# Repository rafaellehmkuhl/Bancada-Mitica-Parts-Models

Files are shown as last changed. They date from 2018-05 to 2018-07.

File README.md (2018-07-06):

Parts Models

This repository contais all the models for the parts used on the project and construction of Bancada Mitica.

All the parts contained here were designed using Solidworks 2016, and so the models are on .SLDPRT extension.
The models used for 3D printed parts are also exported on STL, so anyone can print.
I'm also going to export the .STEP files in the future, so anyone can edit the parts with other softwares, like Fusion360 or Inventor.

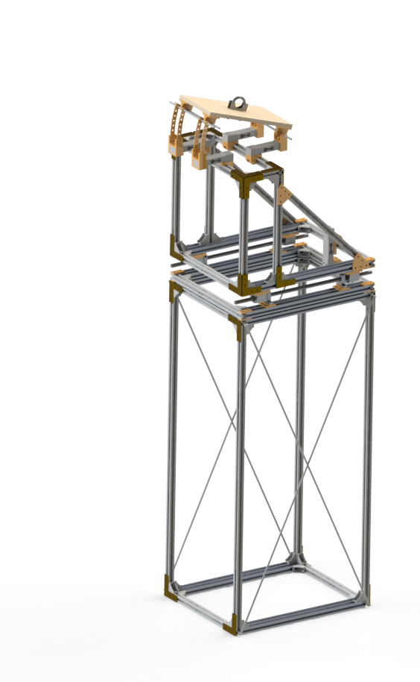
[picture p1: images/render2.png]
Bancada sobre a Torre


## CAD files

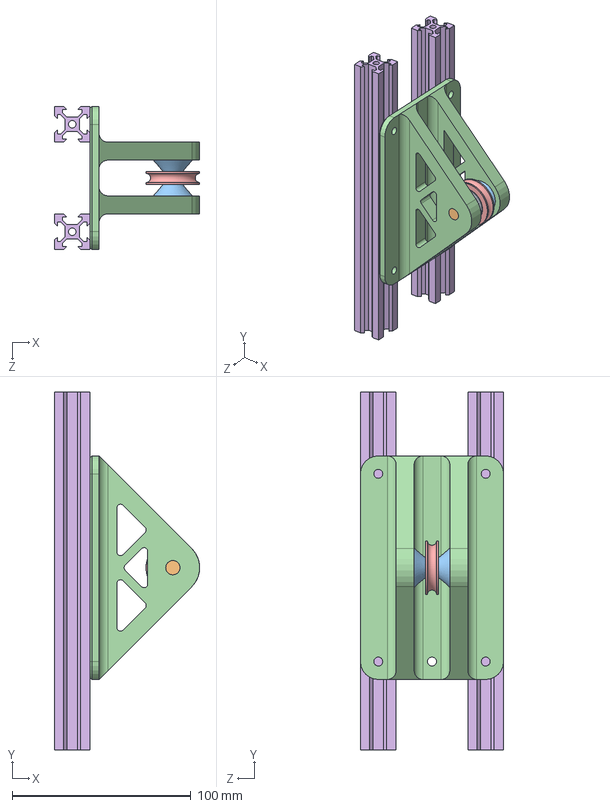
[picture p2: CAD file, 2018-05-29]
Calibraçao/Roldana/Roldana_de_parede.SLDASM
81.2 x 200.0 x 80.0 mm
608RS
Eixo_rolamento
Espaçador_rolamento x 2
Suporte_de_rolamento
Encaixe_corda
Perfil_20x20mm x 2

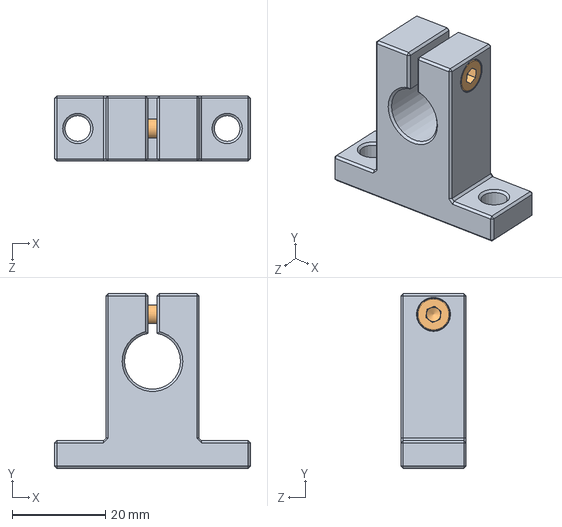
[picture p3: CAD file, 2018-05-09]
Carrinho/Suporte de Eixo SK12/Suporte_SK12.SLDASM
42.0 x 37.5 x 14.0 mm
Shaft support SK12
m4x16

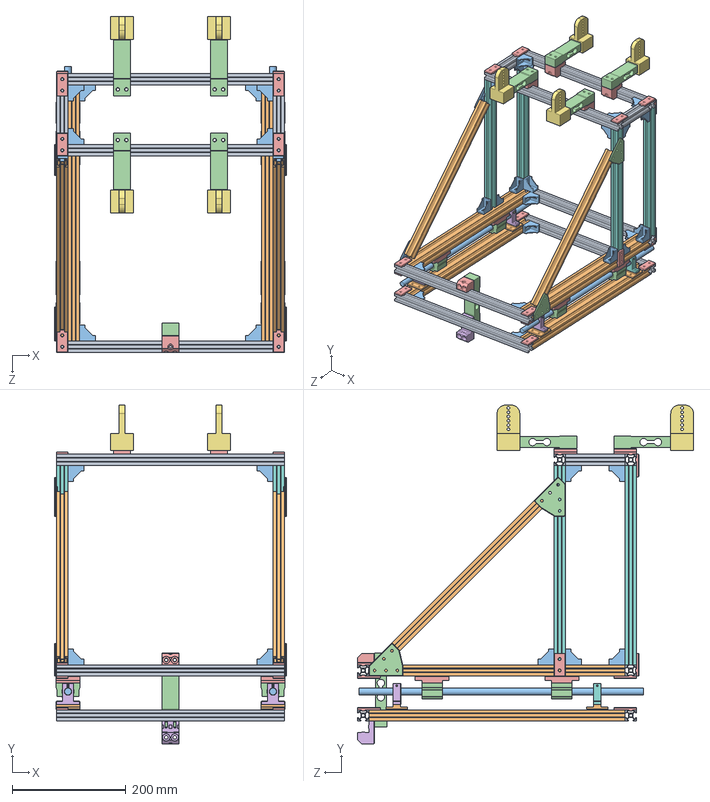
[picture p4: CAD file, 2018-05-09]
Montagens/Balança/Antigas/Balança Final.SLDASM
408.0 x 595.0 x 590.0 mm
20x20x400_profile x 6
20x40x450_profile x 4
cantoneira_20x20 x 28
SC12UU x 4
AdaptadorPillowBlock12 x 4
Shaft support SK12 x 3
m4x16 x 3
EspelharShaft support SK12
Espelharm4x16
AdaptadorSuporteSK12 x 4
EixoLinear12x500mm x 2
load_cell_big_20kg x 5
SuporteCelulaCarga_Reforcado x 5
SuporteCelulaCarga_Reforcado_Ajustavel
EncaixeAsaTraseiro_Alt3 x 4
20x20x350_profile x 4
20x20x105_profile x 2
20x20x410_profile x 2
Placa_lateral_45_esq x 2
Placa_lateral_45_dir x 2
Cantoneira_plana x 20

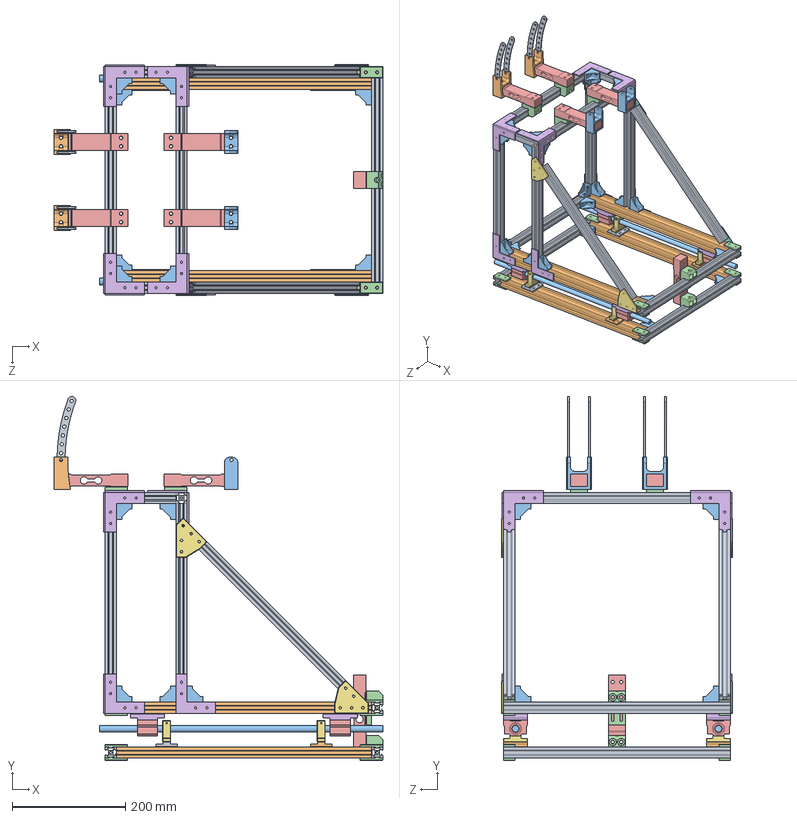
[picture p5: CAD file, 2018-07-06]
Montagens/Balança/Balança.SLDASM
579.5 x 642.0 x 408.0 mm
Perfil_20x20mm x 14
Perfil_20x40mm x 4
Cantoneira_interna_20x20mm x 28
Cantoneira_Plana_impressa_20x40mm x 14
Pillow_Block_SC12UU x 4
Adaptador_para_Pillow_Block_SC12UU x 4
Shaft support SK12 x 4
m4x16 x 4
Adaptador_para_Suporte_SK12_movel x 2
Adaptador_para_Suporte_SK12_fixo x 2
Eixo_Linear_12mm x 2
Suporte_para_Celula_de_Carga_Reforcado x 5
Celula_de_Carga_20kg x 5
Cantoneira_plana_lateral x 16
Placa_Lateral_45graus_impressa_esquerda x 2
Placa_Lateral_45graus_impressa_direita x 2
Peça_de_angulo x 4
Peça_Central x 2
Encaixe_Celula_de_Angulo_Fixo x 2
Suporte_para_Celula_de_Carga_Reforcado_ajustavel

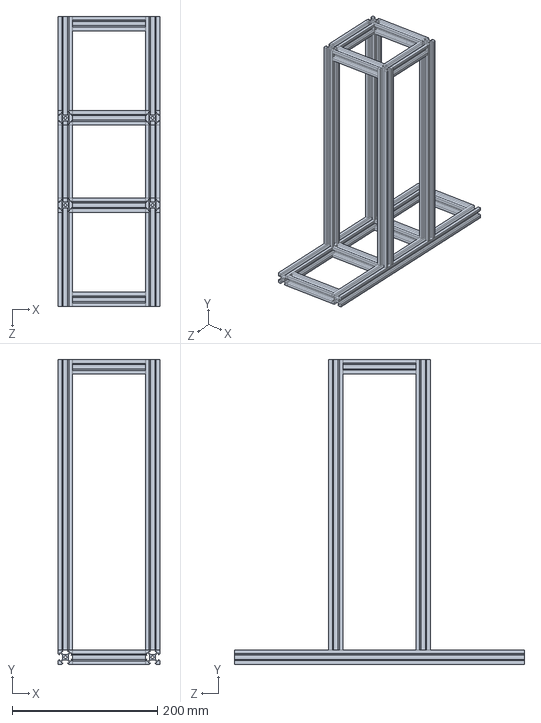
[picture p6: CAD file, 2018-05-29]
Montagens/Calibrador_com_roldana.SLDASM
140.0 x 420.0 x 400.0 mm
Perfil_20x20mm x 14

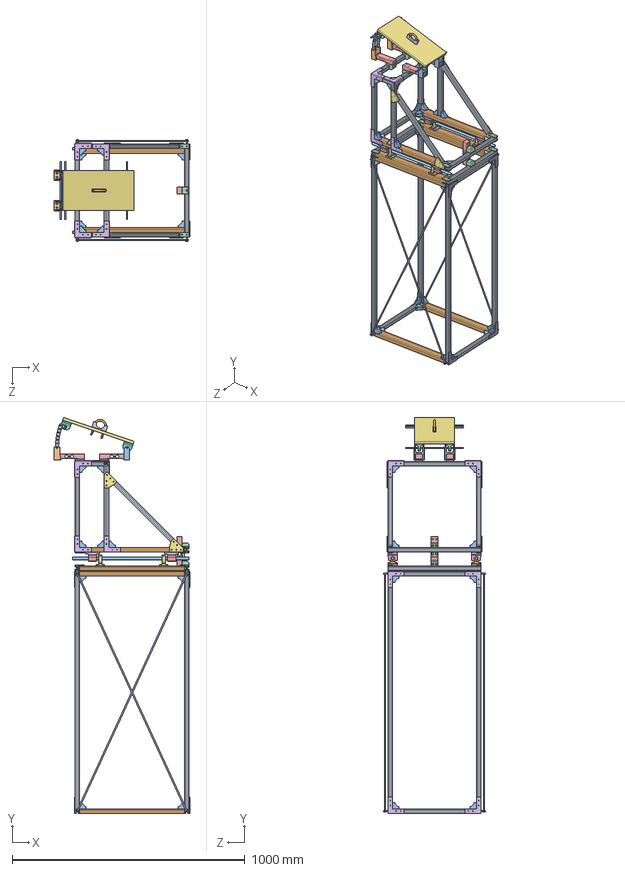
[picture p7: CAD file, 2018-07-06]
Montagens/Montagem completa/Torre_e_balanca.SLDASM
582.5 x 1701.3 x 439.8 mm
Perfil_20x20mm x 22
Perfil_20x40mm x 8
Cantoneira_interna_20x20mm x 52
Cantoneira_Plana_impressa_20x40mm x 14
Pillow_Block_SC12UU x 4
Adaptador_para_Pillow_Block_SC12UU x 4
Shaft support SK12 x 4
m4x16 x 4
Adaptador_para_Suporte_SK12_movel x 2
Adaptador_para_Suporte_SK12_fixo x 2
Eixo_Linear_12mm x 2
Suporte_para_Celula_de_Carga_Reforcado x 5
Celula_de_Carga_20kg x 5
Cantoneira_plana_lateral x 24
Placa_Lateral_45graus_impressa_esquerda x 2
Placa_Lateral_45graus_impressa_direita x 2
Peça_de_angulo x 4
Peça_Central x 2
Encaixe_Celula_de_Angulo_Fixo x 2
Suporte_para_Celula_de_Carga_Reforcado_ajustavel
Parafuso_Olhal_30mm x 8
Cabo_de_aco x 4
Placa
Encaixe_Placa_de_Calibracao x 4
Abracadeira_Grampo_U_Placa_de_Calibracao_Base
Abracadeira_Grampo_U_Placa_de_Calibracao_Argola
Vareta6mm x 3
Extensor x 4

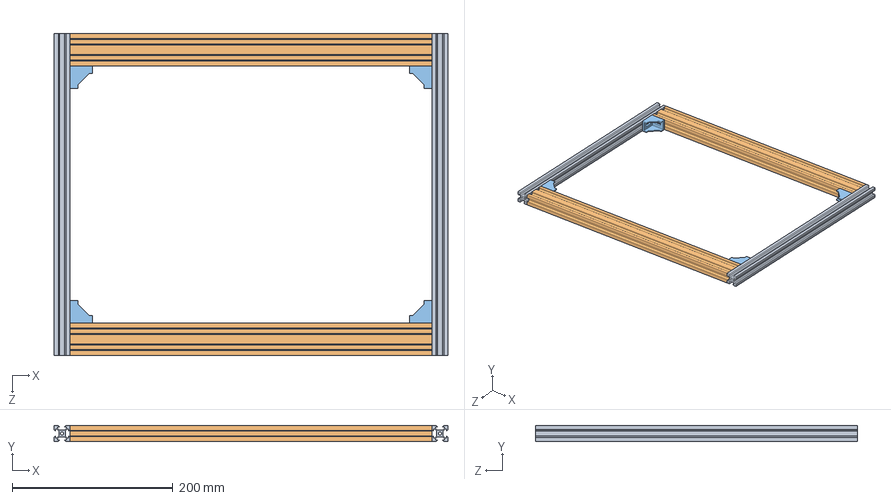
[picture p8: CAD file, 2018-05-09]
Montagens/Quadrado/Quadrado_400x490mm.SLDASM
490.0 x 20.0 x 400.0 mm
Perfil_20x20mm x 2
Perfil_20x40mm x 2
Cantoneira_interna_20x20mm x 4

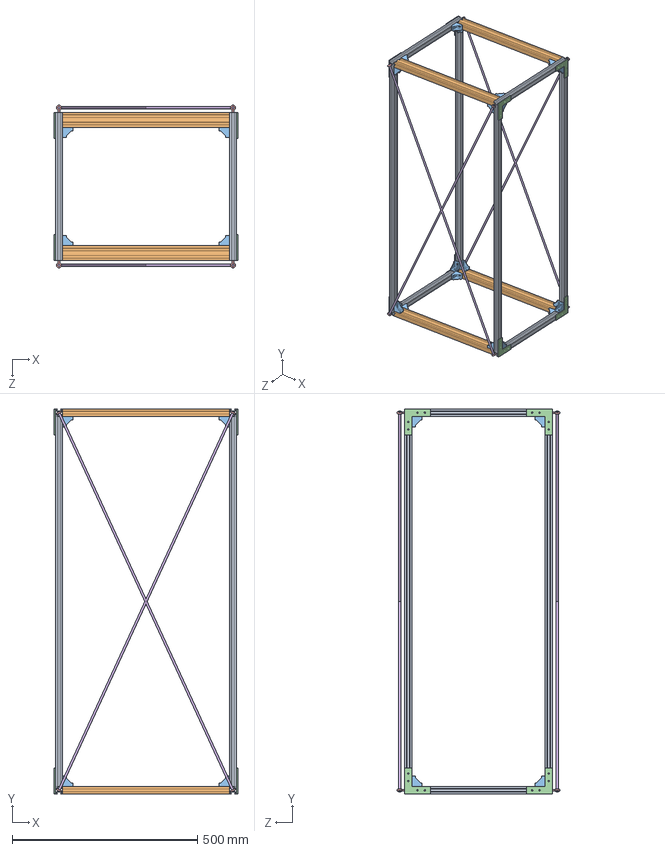
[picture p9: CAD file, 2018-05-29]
Montagens/Torre/Torre.SLDASM
496.0 x 1040.0 x 439.8 mm
Perfil_20x20mm x 8
Perfil_20x40mm x 4
Cantoneira_interna_20x20mm x 24
Cantoneira_plana_lateral x 8
Parafuso_Olhal_30mm x 8
Cabo_de_aco x 4

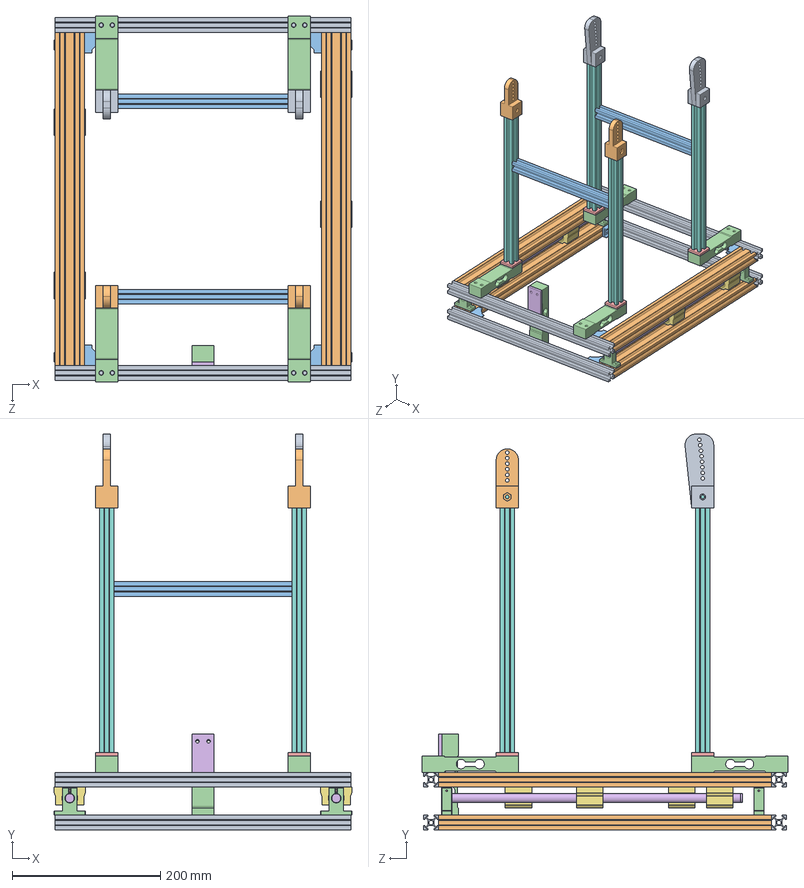
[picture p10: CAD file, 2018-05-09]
Montagens/Balança/Antigas/Balança_Alt2.SLDASM
402.0 x 535.0 x 494.0 mm
20x20x400_profile x 4
20x40x450_profile x 4
cantoneira_20x20 x 8
Shaft support SK12 x 4
m4x16 x 4
EixoLinear12mm x 2
SC12UU x 4
20x20x500_profile x 4
EncaixeAsaDianteiro x 2
EncaixeAsaTraseiro x 2
20x20x200_profile x 2
load_cell_big_20kg x 5
Placa_de_conexao_celula_de_carga x 4
Placa_de_conexao_celula_de_carga_2

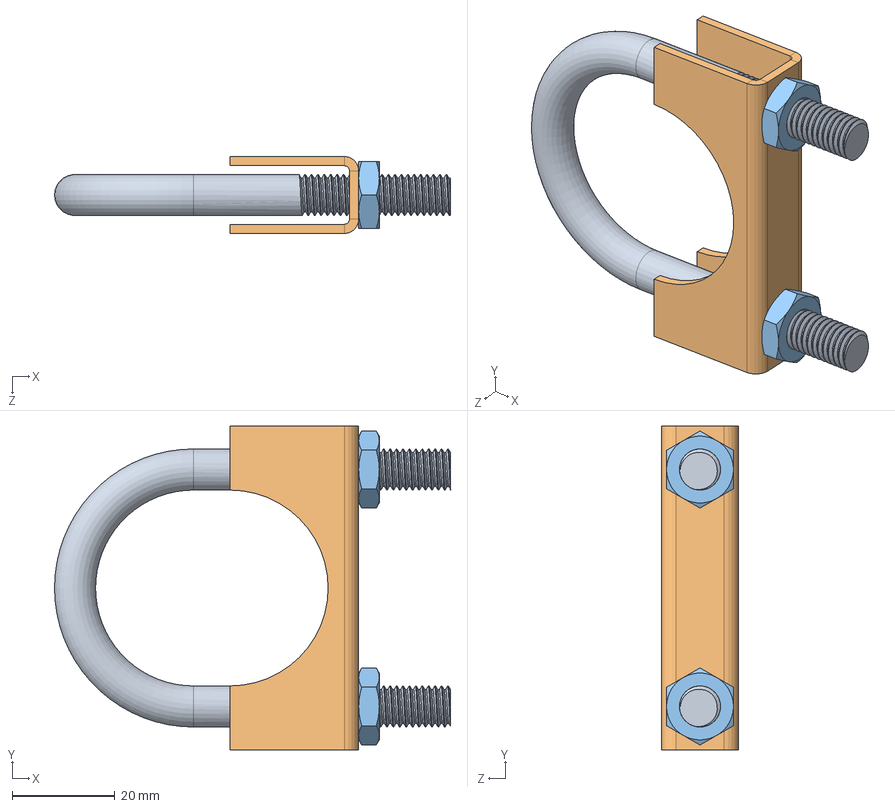
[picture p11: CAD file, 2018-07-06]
Calibraçao/Placa-asa/Abraçadeira/Grampo_Montagem.SLDASM
77.1 x 63.0 x 15.0 mm
Abracadeira_Grampo_U_1.5_
Abracadeira_Grampo_U_1.5_Suporte
hex nut jam_am x 2

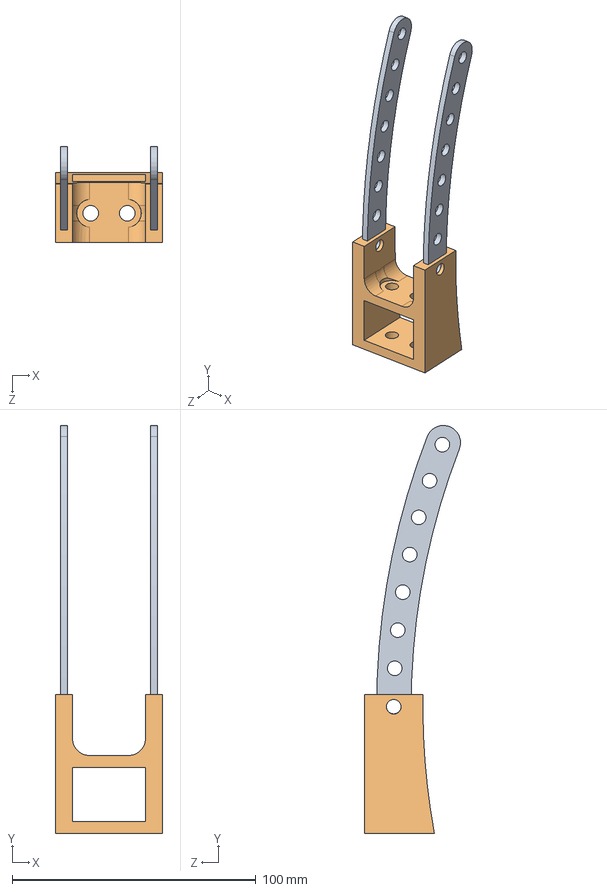
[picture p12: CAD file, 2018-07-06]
Celula de carga/EncaixeCelulaAnguloVariavel/Montagem_Encaixe_Celula_de_Angulo_Variavel.SLDASM
44.0 x 167.5 x 39.4 mm
Peça_de_angulo x 2
Peça_Central

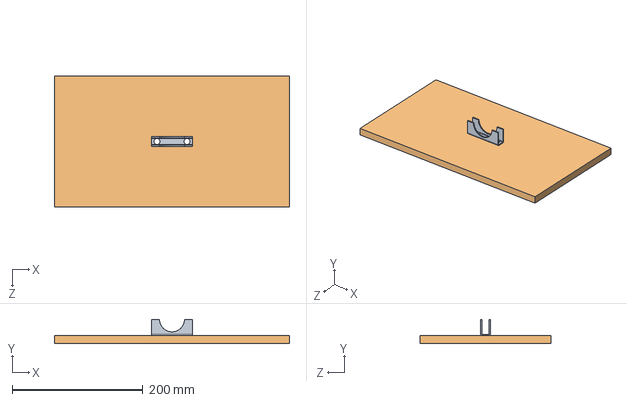
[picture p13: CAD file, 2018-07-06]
Calibraçao/Placa-asa/Montagem_Placa_de_Calibracao.SLDASM
360.0 x 37.0 x 200.0 mm
Placa
Abracadeira_Grampo_U_Placa_de_Calibracao_Base

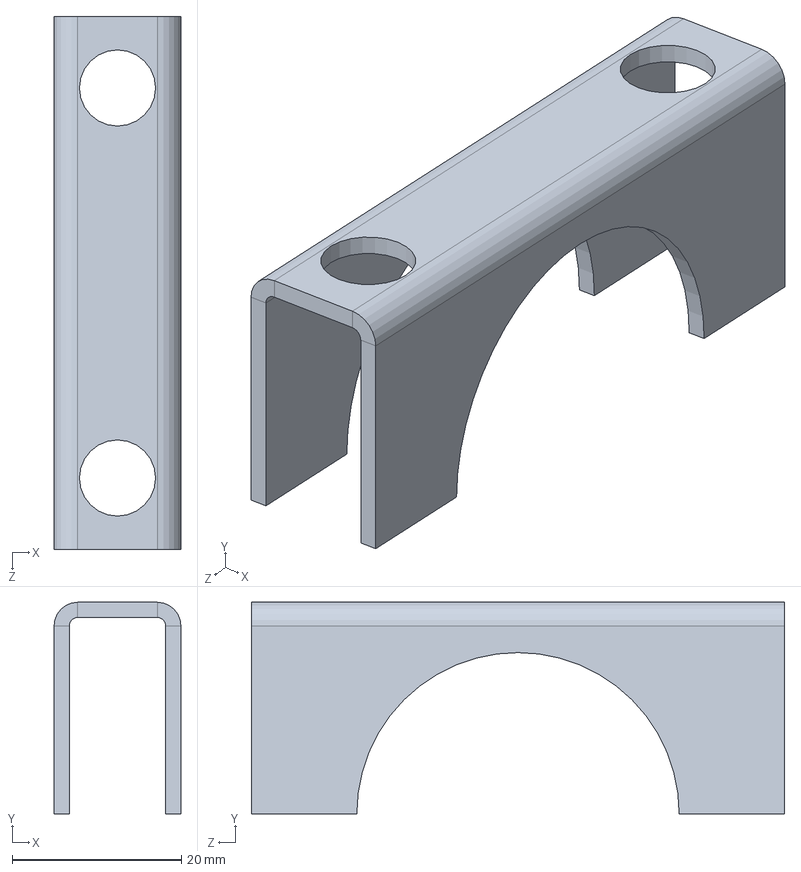
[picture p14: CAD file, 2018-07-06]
Calibraçao/Placa-asa/Abraçadeira/Abracadeira_Grampo_U_Placa_de_Calibracao_Base.SLDPRT
15.0 x 25.0 x 63.0 mm

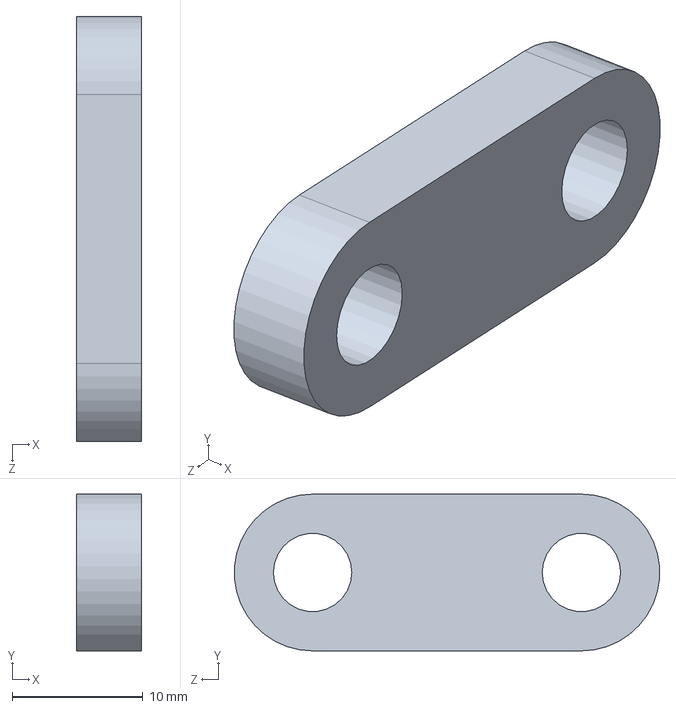
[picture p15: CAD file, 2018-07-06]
Calibraçao/Placa-asa/Extensor.SLDPRT
5.00 x 12.0 x 32.5 mm

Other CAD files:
Carrinho/Suporte de Eixo SK12/EspelharSK12.SLDASM
Montagens/Balança/Antigas/Balança_Alt1.SLDASM
Carrinho/Eixo Linear/Eixo_Linear_12mm.SLDPRT
Carrinho/Pillow Block SC12UU/Adaptador_para_Pillow_Block_SC12UU.SLDPRT
Calibraçao/Placa-asa/Abraçadeira/Abracadeira_Grampo_U_Placa_de_Calibracao_Argola.SLDPRT
Calibraçao/Placa-asa/Encaixe_Placa_de_Calibracao.SLDPRT
Calibraçao/Placa-asa/Encaixe_Placa_de_Calibracao.STL
Calibraçao/Placa-asa/Placa.SLDPRT
Calibraçao/Placa-asa/Vareta6mm.SLDPRT
Calibraçao/Roldana/608RS.SLDPRT
Calibraçao/Roldana/Eixo_rolamento.SLDPRT
Calibraçao/Roldana/Encaixe_corda.SLDPRT
Calibraçao/Roldana/Espaçador_rolamento.SLDPRT
Calibraçao/Roldana/STLs/Encaixe_corda.STL
Calibraçao/Roldana/STLs/Espaçador_rolamento.STL
Calibraçao/Roldana/STLs/Suporte_de_rolamento.STL
Calibraçao/Roldana/Suporte_de_rolamento.SLDPRT
Calibraçao/Roldana/Suporte_de_roldana.SLDPRT
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

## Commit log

2018-04-30 Add current version of the models
    The models added on this commit are still in development, need to be better named and organized.
    There are models for the structure, connections, sensors and others.
    Many parts are designed for additive manufacturing (3d printing).
    [10kg_load_cell.SLDPRT, 20x20x1000_profile.SLDPRT, 20x20x100_profile.SLDPRT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]
2018-05-08 Complete re-design and re-organize
    - Almost all files were renamed and reorganized.
    - All the aluminium profiles changed from hardcoded dimensions to parametrized dimensions, this is, there is only one aluminium 2020 profile, and the diferent lenghts are archived using internal Soli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
    - STL files weren't updated
    [10kg_load_cell.SLDPRT, 20x20x1000_profile.SLDPRT, 20x20x100_profile.SLDPRT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]
2018-05-29 Add steel cables on both sides
    The cable is needed to gain rigidity on the structure.
    Initialy, only one cable would be added on each side, but as noticed on construction, this makes the structure get skewed, so an "X" will be made on each side.
    [Balança.SLDASM, Cabo_de_aco.SLDPRT, Parafuso_Olhal_30mm.SLDPRT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]
2018-05-29 Add calibration pulley
    This calibration device acts as a pulley to be fixed on the wall to aligne a rope with the horizon and simulate a drag force.
    [608RS.SLDPRT, Calibrador_com_roldana.SLDASM, Eixo_rolamento.SLDPRT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]
2018-07-06 Added Cabo de Aço lateral
    This cable is meant to give rigidity on the pitch axis.
2018-07-06 Create Roldana
    Creates Roldana to allow calibration of Cells inhouse.
    [608RS.SLDPRT, Eixo_rolamento.SLDPRT, Encaixe_corda.SLDPRT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]
2018-07-06 Create Placa de Calibraçao
    The "Placa de Calibraçao" allows the calibration of all cells together, and also allows to find the coefficients of fake lift and shear.
    [Abracadeira_Grampo_U_Placa_de_Calibracao_Argola.SLDPRT, Abracadeira_Grampo_U_Placa_de_Calibracao_Base.SLDPRT, Encaixe_Placa_de_Calibracao.SLDPRT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]
2018-07-06 Reorganize files
    [AdaptadorPillowBlock12.STL, AdaptadorSuporteSK12.STL, AdaptadorSuporteSK12_movel.STL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]
2018-07-06 Update LoadCell - Wing adaptor
    Create new adaptor to allow discrete change on Angle of Attack.
    [10kg_load_cell.SLDPRT, EncaixeAsaDianteiro.SLDPRT, EncaixeAsaDianteiro.STL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]
2018-07-06 Update assemblies
    [Balança.SLDASM, Torre_e_balanca.SLDASM]
